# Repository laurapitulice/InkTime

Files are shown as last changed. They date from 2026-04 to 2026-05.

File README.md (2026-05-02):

# ⌚ "InkTime smartwatch" - PCB layout in Autodesk Fusion360
InkTime is an e-paper smartwatch designed for month-class battery life, sunlight-readable time-first UX, and essential phone notifications with basic activity
tracking.
Developed in Autodesk Fusion 360, the PCB layout adheres to the precise dimensions and mounting requirements of the wearable chassis, ensuring a seamless fit and optimal component placement.

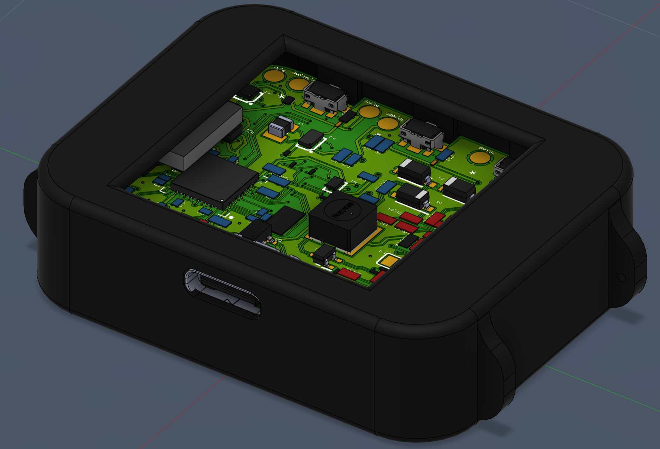
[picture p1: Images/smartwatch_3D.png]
Smartwatch Preview


---

## Hardware Diagram
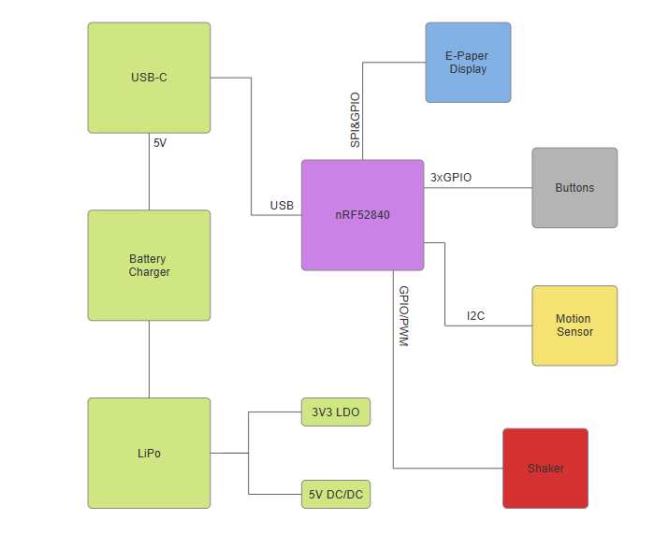
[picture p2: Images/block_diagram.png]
Hardware Diagram


This is an open-hardware wearable based on the nRF52840 microcontroller.

---

## System Architecture

### 1. Microcontroller (MCU)
- **Chip:** Nordic nRF52840 (Cortex-M4F @ 64MHz)
- **Memory:** 1MB Flash, 256KB RAM
- **Radio:** Bluetooth 5.4 Low Energy with integrated ceramic antenna
- **Oscillators:** 32MHz (operational) and 32.768kHz (sleep mode/RTC)

### 2. Power Management
- **Li-Po Charger:** BQ25180 (I2C control, programmable current)
- **Voltage Regulator:** RT6100 Buck-Boost (stable 3.3V output)
- **Battery Monitoring:** MAX17048 Fuel Gauge (ModelGauge algorithm)
- **Charging Interface:** USB-C with USBLC6-2 ESD protection

### 3. Display (E-Paper)
- **Type:** Electronic Paper Display (EPD)
- **Interface:** SPI + Power Gating Control (PWR_EPD)
- **Drive Circuit:** On-board integrated Boost converter (MBR0530 Diodes, L5 10uH) for VGH/VGL generation

### 4. Sensors and Feedback
- **IMU:** BMA421 (Ultra-low power accelerometer connected via I2C)
- **Haptic:** DRV2605 (Vibration driver with integrated effects library via I2C)
- **Input:** 3 mechanical buttons (UP, ENTER, DOWN) with filtering circuits

### 5. Communication Interfaces (I2C Mapping)
| Component | Function | Interface |
| :--- | :--- | :--- |
| **BMA421** | Motion Sensor | I2C |
| **MAX17048** | Battery Status | I2C |
| **DRV2605** | Vibration Motor | I2C |
| **BQ25180** | Charging | I2C |

---

## nRF52840 Pin Mapping

| Pin nRF52840 | Signal | Component | Interface |
|---|---|---|---|
| P0.00/XL1 | XL1 | Crystal X2 (32.768kHz) | XTAL |
| P0.01/XL2 | XL2 | Crystal X2 (32.768kHz) | XTAL |
| P0.05/AIN3  | EPD_CS | E-Paper (J1 FPC) | SPI CS |
| P0.06 | SDA | BMA423, BQ25180, MAX17048, DRV2605 | I2C SDA |
| P0.07 | SCL | BMA423, BQ25180, MAX17048, DRV2605 | I2C SCL |
| P0.08 | IMU_INT1 | BMA423 | GPIO Input |
| P1.08 | IMU_INT2 | BMA423 | GPIO Input |
| P0.11 | PMIC_INT | BQ25180 | GPIO Input |
| P0.12 | HAPTIC_EN  | DRV2605 | GPIO |
| VBUS | VBUS | USB-C (J4) | Power |
| D- | D- | USB-C (J4) / USBLC6 | USB |
| D+ | D+ | USB-C (J4) / USBLC6 | USB |
| P0.13 | SW_UP | Buton Up | GPIO Input |
| P0.14 | SW_ENT | Buton Enter | GPIO Input |
| P0.15 | EPD_DC | E-Paper (J1 FPC) | SPI DC |
| P0.16 | EPD_RST | E-Paper (J1 FPC) | GPIO |
| P0.17 | EPD_BUSY | E-Paper (J1 FPC) | GPIO Input |
| P0.18/RESET | RESET | TC2030-IDC | SWD/GPIO |
| SWDCLK | SWDCLK | TC2030-IDC | SWD |
| SWDIO | SWDIO | TC2030-IDC | SWD |
| P1.02 | SW_DN | Buton Down | GPIO Input |
| P0.10/NFC2  | ALERT | MAX17048 | GPIO Input |
| ANT | RF | Antena 2450AT18B100E | RF |
| P0.02/AIN0  | SCK | E-Paper (J1 FPC) | SPI SCK |
| P0.03/AIN1  | MOSI | E-Paper (J1 FPC) | SPI MOSI |

---

## Hardware Design & PCB Layout

### 1. Component Placement Strategy
The layout process followed a "mechanical-first" approach to ensure perfect alignment with the enclosure:
* **Mechanical Constraints:** Critical components (USB-C connector, side buttons, and the E-Paper FPC connector) were placed first and **locked** to prevent accidental displacement during the routing process.
* **Logical Grouping:** Components were clustered according to their schematic blocks. ICs were placed centrally to their respective functional areas to minimize signal path lengths.
* **Top-Side Only:** All components are placed exclusively on the **TOP layer** to simplify manufacturing and thermal management.
* **Microcontroller:** The **nRF52840** is positioned relatively in the center of the board to maintain balanced access to all peripheral blocks it commands.
* **User Interface:** Test points and tactile buttons were strategically placed along the board edges for easy access during debugging and final assembly.

### 2. Design Rules & Routing
The board utilizes a **2-layer stack-up** with a focus on signal integrity and power stability:
* **Power & Ground:** 
    * Power traces are maintained at a width of **≥ 0.3 mm**, while signal traces are **≥ 0.15 mm**.
    * **Daisy-chaining** was avoided for power; instead, a **branching topology** was used to prevent ground/power loops.
    * Solid **GND polygon pours** are implemented on both Top and Bottom layers, connected by stitching vias to ensure a low-impedance return path.
* **Decoupling:** 100nF capacitors are placed as close as possible to the power pins of each integrated circuit to filter high-frequency noise.
* **Geometry:** Strictly utilized **45° angles** and smooth miters; 90° bends were eliminated to prevent signal reflections and manufacturing "acid traps."
* **Trace Optimization:** Routes were kept as short as possible. Via usage was minimized, only added when top-layer density required a transition to the bottom layer. Traces were kept away from sensitive areas like the crystal oscillator and inductors.

### 3. RF & EMI Management
Special precautions were taken for the wireless and power sections:
* **Antenna Integrity:** The ceramic antenna is isolated in the top-right corner. A strict **keep-out zone** (no copper, traces, or vias) was maintained around the antenna to prevent signal degradation and interference.
* **Inductor Orientation:** Series inductors (**L2, L3**) are positioned **perpendicularly** (90°) to each other to minimize mutual magnetic coupling and unwanted electromagnetic field amplification.
* **Clean Zones:** No traces were routed underneath inductors, the crystal oscillator, or mounting holes to maintain signal purity.

### 4. Design Rule Check (DRC) & Intentional Exceptions
The design was verified against custom DRC rules. Some errors were manually reviewed and accepted based on specific design requirements:
* **Dimension/Clearance Errors:** The USB-C connector and buttons extend slightly beyond the PCB edge for enclosure alignment. These "Dimension" errors are intentional and neglected.
* **Via-in-Pad:** In extremely dense areas where traditional routing was inaccessible, **0.15 mm micro-vias** were placed within pads to facilitate connectivity.
* **3D Modeling:** 3D models were applied to bulky and critical components for enclosure fit-checks; small passives use standard footprint placeholders.

### 5. Final Verification
* **Clear Silkscreen:** All labels and component designators were cleaned and oriented for high legibility (clear and readable).
* **Connectivity Audit:** A final manual and automated netlist audit was performed to ensure 100% routing completion.
* **Manufacturing Ready:** DRC was cleared of all non-intentional errors, ensuring the board meets professional fabrication capabilities.
  
---

## Debug and Programming
- **SWD:** Programming and debugging via Tag-Connect TC2030 connector
- **USB:** Serial communication and charging

---

## Power Consumption and Battery Life

The device is optimized for ultra-low power operation, leveraging the nRF52840's sleep states and power-gating techniques for high-voltage peripherals.

### Estimated Current Consumption
| Operating Mode | Active Components | Estimated Current |
| :--- | :--- | :--- |
| **Deep Sleep** | MCU (System OFF), Fuel Gauge (Sleep) | ~10 µA |
| **Standby (Idle)** | MCU (System ON), IMU (Low-power) | ~0.8 mA |
| **EPD Refresh** | MCU, EPD Boost Circuit, Display | ~12 mA (peak) |
| **Haptic Alert** | MCU, Haptic Driver + Motor | ~80 mA (peak) |

### Battery Life Estimation
Based on a **200mAh** Li-Po battery:
- **Static Time (Always-on):** Over 1 year (EPD retains the image without power).
- **Typical Usage:** ~10-12 days (with BLE active and 1 refresh/hour).
- **Heavy Usage:** ~4-5 days (frequent haptic notifications and updates).
  
---

## Bill of Materials (BOM)

| Component | Description | Qty | Manufacturer | Part Number | Datasheet |
| :--- | :--- | :--- | :--- | :--- | :--- |
| **Microcontroller** | nRF52840 (AQFN-74) | 1 | Nordic Semiconductor | NRF52840_QF | [Link](https://files.seeedstudio.com/wiki/XIAO-BLE/Nano_BLE_MCU-nRF52840_PS_v1.1.pdf) |
| **Antenna** | 2.45GHz Chip Antenna | 1 | Johanson Technology | 2450AT18B100E | [Link](https://www.johansontechnology.com/datasheets/2450AT18B100.pdf) |
| **Accelerometer** | Triaxial low-g 12bit Sensor | 1 | Bosch Sensortec | BMA423 | [Link](https://watchy.sqfmi.com/assets/files/BST-BMA423-DS000-1509600-950150f51058597a6234dd3eaafbb1f0.pdf) |
| **Battery Charger** | Li-Ion/Polymer Charger IC | 1 | Texas Instruments | BQ25180YBGR | [Link](https://www.ti.com/product/BQ25180) |
| **Haptic Driver** | Driver for ERM/LRA | 1 | Texas Instruments | DRV2605YZFR | [Link](https://www.ti.com/product/DRV2605) |
| **Voltage Regulator** | Buck-Boost DC-DC | 1 | Richtek | RT6160AWSC | [Link](https://www.richtek.com/Products/Switching%20Regulators/Buck-Boost%20Converter/RT6160A) |
| **Fuel Gauge** | 1-Cell/2-Cell Fuel Gauge | 1 | Analog Devices | MAX17048G+T10 | [Link](https://www.analog.com/en/products/max17048.html) |
| **Connector (FPC)** | 0.5mm FPC RA SMT 24Ckt | 1 | Molex | 503480-2400 | [Link](https://www.molex.com/en-us/products/part-detail/5034802400) |
| **Connector (USB)** | USB Type-C 16-pin | 1 | Kinghelm | KH-TYPE-C-16P | [Link](https://jlcpcb.com/api/file/downloadByFileSystemAccessId/8588905154556923904) |
| **ESD Protection** | Low Cap. ESD Protection | 1 | STMicroelectronics | USBLC6-2SC6Y | [Link](https://www.st.com/en/protection-devices/usblc6-2.html) |
| **MOSFET (P)** | P-channel 20V/4.2A | 1 | Diodes Inc. | DMG2305UX-7 | [Link](https://www.lcsc.com/datasheet/C469327.pdf) |
| **MOSFET (N)** | N-channel 30V 1.5A | 1 | Vishay Siliconix | SI1308EDL-T1-GE3 | [Link](https://www.lcsc.com/datasheet/C469327.pdf) |
| **Schottky Diode** | 30V 0.5A Schottky | 3 | ON Semiconductor | MBR0530 | [Link](https://www.onsemi.com/pdf/datasheet/mbr0530t1-d.pdf) |
| **Inductor** | SMD Inductor 0.47µH | 1 | TDK | FTC252012SR47MBCA | [Link](https://jlcpcb.com/partdetail/6763488-FTC252012SR47MBCA/C5832368) |
| **Inductor** | Power Inductor 68uH | 1 | Wurth Electronics | 744043680 | [Link](https://www.we-online.com/en/components/products/WE-TPC) |
| **Switches** | Tactile Switches | 3 | Panasonic | EVP-AKE31A | [Link](https://wmsc.lcsc.com/wmsc/upload/file/pdf/v2/lcsc/2301111010_PANASONIC-EVPAKE31A_C569760.pdf) |
| **Crystals** | 32MHz & 32.768kHz | 2 | Generic/Nordic | X1, X2 | [Link1](https://wmsc.lcsc.com/wmsc/upload/file/pdf/v2/lcsc/2312080231_NDK-NX2016SA-32MHZ-EXS00A-CS11336_C6134317.pdf), [Link2](https://jlcpcb.com/partdetail/SeikoEpson-FC_135_32_7680KAA3/C2650472) |
| **Test Connector** | CABLE ADAPTER 6 POS | 1 | Tag Connect | TC2030-IDC | [Link](https://www.tag-connect.com/wp-content/uploads/bsk-pdf-manager/2019/12/TC2030-IDC-Datasheet-Rev-B.pdf) |

** The design and implementation of this PCB were based on the technical guidelines and reference designs provided by [OCW](https://ocw.cs.pub.ro/courses/tsc/proiect2026).

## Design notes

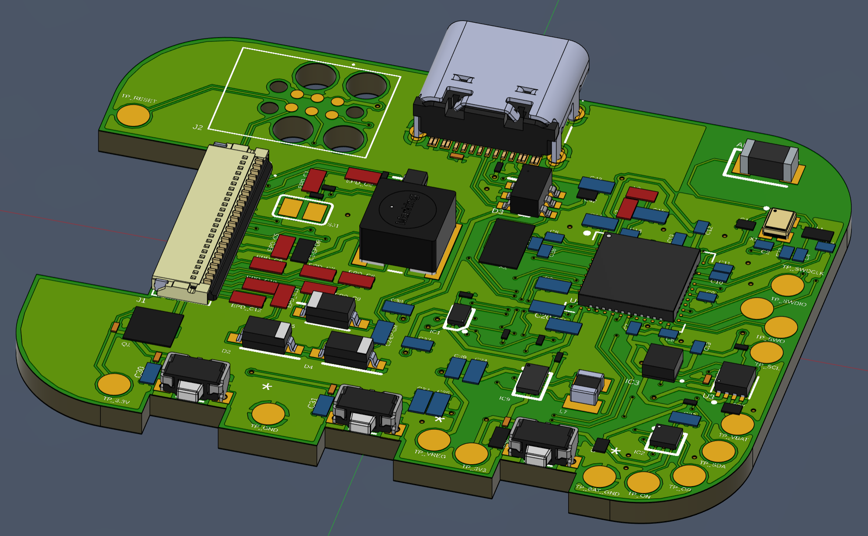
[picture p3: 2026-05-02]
Images/PCB_3D_side_view.png

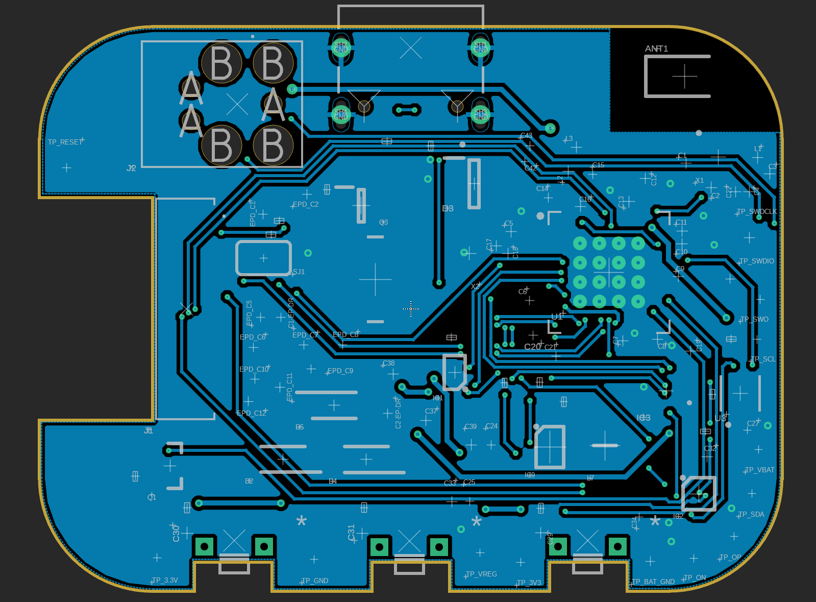
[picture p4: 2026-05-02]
Images/PCB_2D_bottom_layer.png

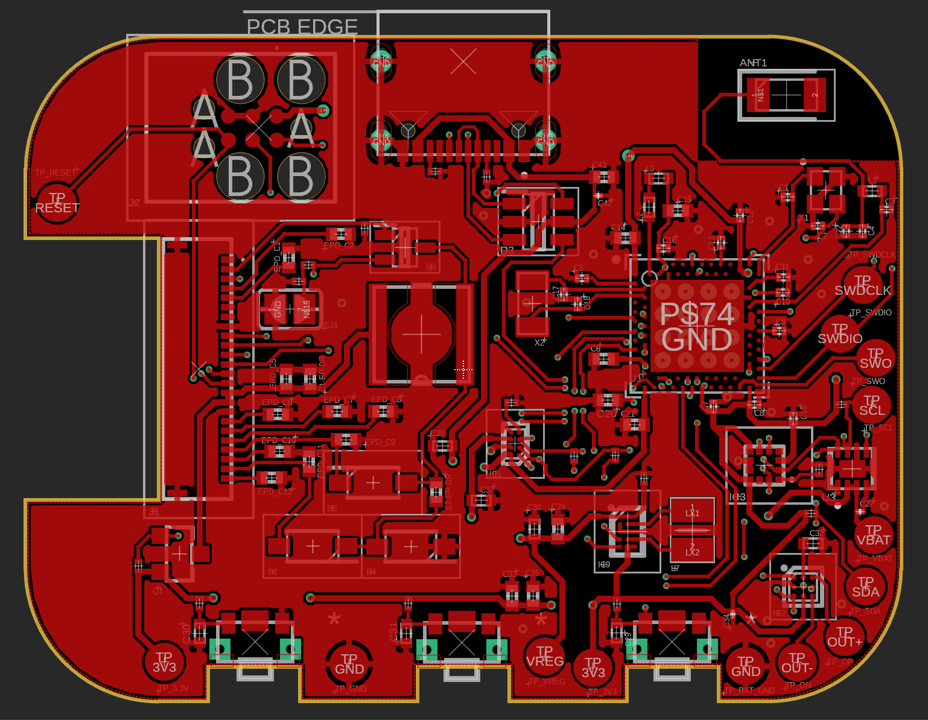
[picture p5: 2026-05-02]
Images/PCB_2D_top_layer.png

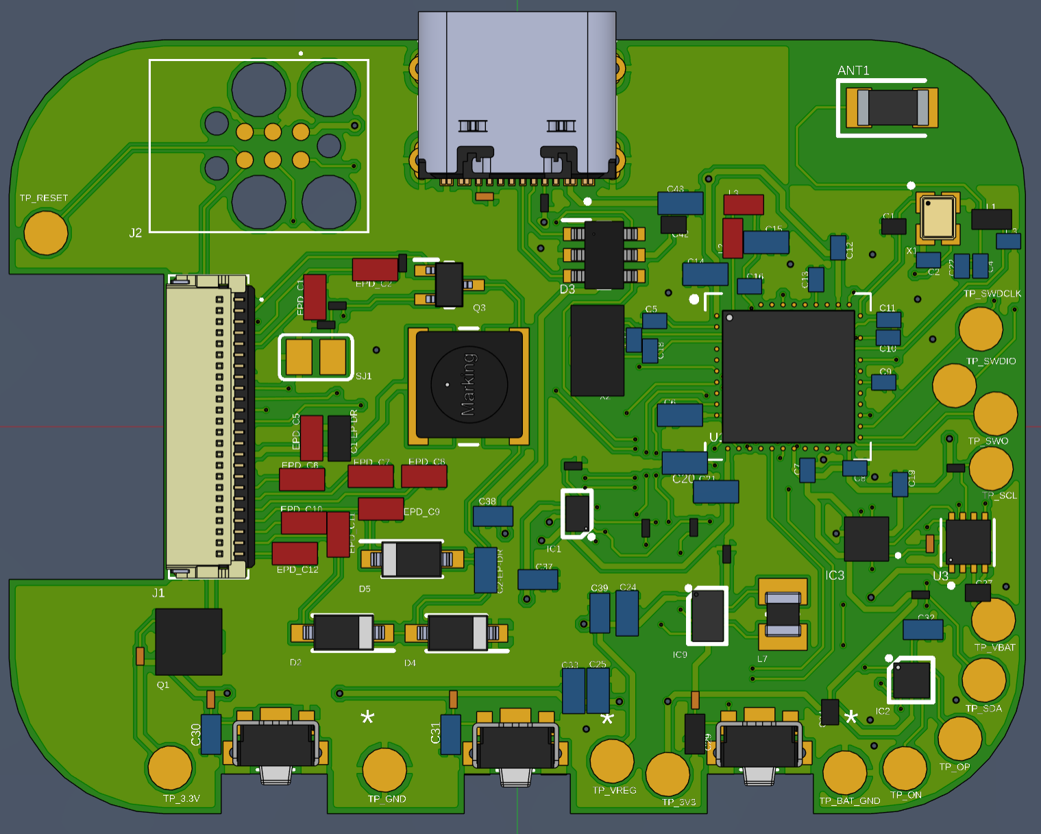
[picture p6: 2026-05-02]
Images/PCB_3D_top_view.png

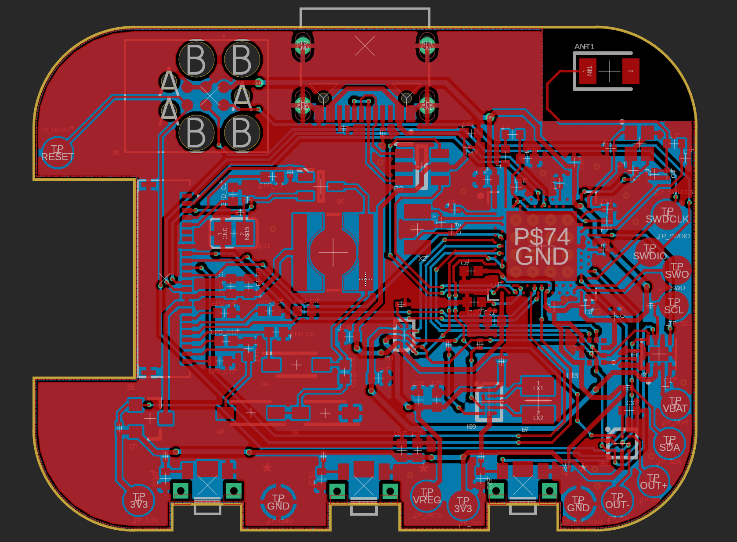
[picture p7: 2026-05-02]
Images/PCB_2D.png

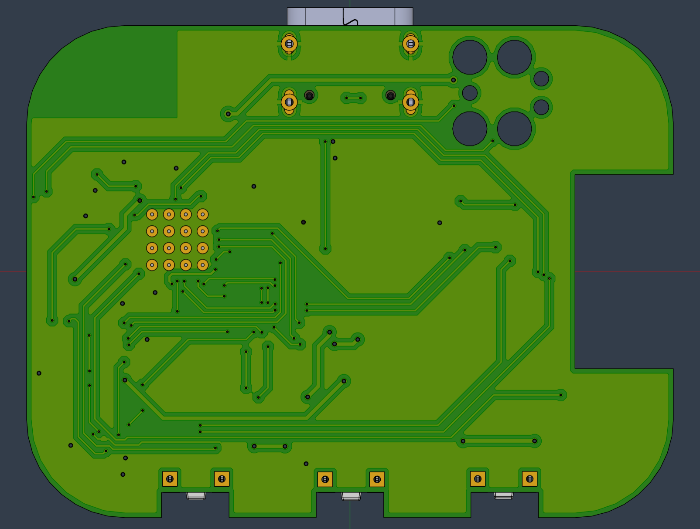
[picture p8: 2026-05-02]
Images/PCB_3D_bottom_view.png

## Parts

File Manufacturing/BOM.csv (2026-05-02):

Qty | Value | Device | Package | Parts | Description | ARROW_PART_NUMBER | ARROW_PRICE-STOCK | AVAILABILITY | CHECK_PRICES | COPYRIGHT | DESCRIPTION | DIGI-KEY_PART_NUMBER_1 | DIGI-KEY_PART_NUMBER_2 | DIGI-KEY_PART_NUMBER_3 | HEIGHT | JLCPCB | MANUFACTURER_NAME | MANUFACTURER_PART_NUMBER | MF | MFR_NAME | MOUSER_PART_NUMBER | MOUSER_PRICE-STOCK | MP | PACKAGE | POPULARITY | PRICE | PROD_ID | PURCHASE-URL | SNAPEDA_LINK | TP_SIGNAL_NAME | VALUE
1 | 0 | CPF0201D7K68C1_CPF0201D7K68C1 | CPF0201D7K68C1_0201 | R3 | 7.68k 0201 Thin Film Surface Mount Fixed Resistor +/-0.5% 0.031W CPF0201D7K68C1
2 | 0 | ERA-1AEB3401C_CPF0201D7K68C1 | ERA-1AEB3401C_0201 | R2, R4 | 7.68k 0201 Thin Film Surface Mount Fixed Resistor +/-0.5% 0.031W CPF0201D7K68C1
1 | 0 | ESP32_C6_LIBRARY_7_JUMPER_SJ | ESP32_C6_LIBRARY_7_JUMPER_SJ | SJ1 | SMD solder JUMPER |  |  |  |  |  |  |  |  |  |  |  |  |  |  |  |  |  |  |  | 3
1 | 0.1uF | GRM011R60J152KE01L_1_GRM011R60J152KE01L | GRM011R60J152KE01L_1_0201 | C23 | Check availability
3 | 0.1uF | GRM011R60J152KE01L_2_GRM011R60J152KE01L | GRM011R60J152KE01L_2_CAPC0201X13N | C27, C34, C42 | Check availability |  |  | In Stock | https://www.snapeda.com/parts/GRM011R60J152KE01L/Murata/view-part/?ref=eda |  | SMD Capacitor X5R(EIA) with Capacitance: 1500pF Tol. 10%. Rated Voltage: 6.3Vdc |  |  |  |  |  |  |  | Murata |  |  |  | GRM011R60J152KE01L | 0201 Murata |  | None |  |  | https://www.snapeda.com/parts/GRM011R60J152KE01L/Murata/view-part/?ref=snap
1 | 0.47 | ERA-1AEB3401C_CPF0201D7K68C1 | ERA-1AEB3401C_0201 | R1_EP_DR | 7.68k 0201 Thin Film Surface Mount Fixed Resistor +/-0.5% 0.031W CPF0201D7K68C1
1 | 1.0uF | PERFECT_0402_CAP_0402 | PERFECT_0402_0402 | C15 | 0402 (1005 Metric)
5 | 100nF | NORDIC_NRF_3_CAPACITOR_0201_L | NORDIC_NRF_3_RESC0201_L | C5, C7, C8, C12, C19 | Generic chip capacitor
1 | 100pF | NORDIC_NRF_3_CAPACITOR_0201_L | NORDIC_NRF_3_RESC0201_L | C11 | Generic chip capacitor
1 | 10K | CPF0201D7K68C1_CPF0201D7K68C1 | CPF0201D7K68C1_0201 | R_PWR_EPD | 7.68k 0201 Thin Film Surface Mount Fixed Resistor +/-0.5% 0.031W CPF0201D7K68C1
2 | 10K | ERA-1AEB3401C_CPF0201D7K68C1 | ERA-1AEB3401C_0201 | R2_EP_DR, R9 | 7.68k 0201 Thin Film Surface Mount Fixed Resistor +/-0.5% 0.031W CPF0201D7K68C1
3 | 10k | CPF0201D7K68C1_CPF0201D7K68C1 | CPF0201D7K68C1_0201 | R5, R7, R8 | 7.68k 0201 Thin Film Surface Mount Fixed Resistor +/-0.5% 0.031W CPF0201D7K68C1
1 | 10uF | NORDIC_NRF_3_CAPACITOR_0402_L | NORDIC_NRF_3_RESC0402_L | C39 | Generic chip capacitor
2 | 10uF | PERFECT_0402_CAP_0402 | PERFECT_0402_0402 | C1-EP-DR, C24 | 0402 (1005 Metric)
1 | 10uH | NORDIC_NRF_2_INDUCTOR_0402_L | NORDIC_NRF_2_RESC0402_L | L2 | Generic chip inductor
4 | 12pF | NORDIC_NRF_3_CAPACITOR_0201_L | NORDIC_NRF_3_RESC0201_L | C1, C2, C17, C18 | Generic chip capacitor
1 | 15nH | NORDIC_NRF_2_INDUCTOR_0402_L | NORDIC_NRF_2_RESC0402_L | L3 | Generic chip inductor
2 | 1pF | NORDIC_NRF_3_CAPACITOR_0201_L | NORDIC_NRF_3_RESC0201_L | C3, C4 | Generic chip capacitor
6 | 1uF | NORDIC_NRF_3_CAPACITOR_0402_L | NORDIC_NRF_3_RESC0402_L | C29, C30, C31, C32, C37, C38 | Generic chip capacitor
10 | 1uF/50V | PERFECT_0402_CAP_0402 | PERFECT_0402_0402 | EPD_C1, EPD_C2, EPD_C5, EPD_C6, EPD_C7, EPD_C8, EPD_C9, EPD_C10, EPD_C11, EPD_C12 | 0402 (1005 Metric)
1 | 2.2 | ERA-1AEB3401C_CPF0201D7K68C1 | ERA-1AEB3401C_0201 | R_TYPE_SEL | 7.68k 0201 Thin Film Surface Mount Fixed Resistor +/-0.5% 0.031W CPF0201D7K68C1
3 | 2025-10-22_07-23-44_LIBRARY_EVP-AKE31ASW_EVP-AKE31A_PAN | 2025-10-22_07-23-44_LIBRARY_EVP-AKE31ASW_EVP-AKE31A_PAN | 2025-10-22_07-23-44_LIBRARY_SW_EVP-AKE31A_PAN | SW_DN, SW_ENT, SW_UP |  |  |  |  |  | Copyright (C) 2025 Ultra Librarian. All rights reserved. |  | P123437TR-ND | P123437CT-ND | P123437DKR-ND |  |  | Panasonic | EVP-AKE31A
2 | 22uF | PERFECT_0402_CAP_0402 | PERFECT_0402_0402 | C25, C33 | 0402 (1005 Metric)
1 | 2450AT18B100E_2450AT18B100E | 2450AT18B100E_2450AT18B100E | 2450AT18B100E_ANTC3216X140N | ANT1 | Antennas 2.45GHz ANTENNA | 2450AT18B100E | https://www.arrow.com/en/products/2450at18b100e/johanson-dielectrics?utm_currency=USD&region=nac |  |  |  | Antennas 2.45GHz ANTENNA |  |  |  | 1.4mm |  | JOHANSON TECHNOLOGY | 2450AT18B100E |  |  | 609-2450AT18B100E | https://www.mouser.co.uk/ProductDetail/Johanson-Technology/2450AT18B100E?qs=yCnrNFeXz%252Bh5MFsFIXGZGA%3D%3D
1 | 3.9nH | NORDIC_NRF_2_INDUCTOR_0402_L | NORDIC_NRF_2_RESC0402_L | L1 | Generic chip inductor
1 | 32.768kHz | NORDIC_NRF_1_XTAL_32KHZ | NORDIC_NRF_1_XTAL_3215_N | X2
1 | 32MHz | NORDIC_NRF_XTAL_32MHZ | NORDIC_NRF_BT-XTAL_2016_N | X1
2 | 3K3 | ERA-1AEB3401C_CPF0201D7K68C1 | ERA-1AEB3401C_0201 | R17, R18 | 7.68k 0201 Thin Film Surface Mount Fixed Resistor +/-0.5% 0.031W CPF0201D7K68C1
5 | 4.7uF | PERFECT_0402_CAP_0402 | PERFECT_0402_0402 | C6, C14, C20, C21, C43 | 0402 (1005 Metric)
1 | 4.7uF/25V | PERFECT_0402_CAP_0402 | PERFECT_0402_0402 | C2-EP-DR | 0402 (1005 Metric)
1 | 47nF | NORDIC_NRF_3_CAPACITOR_0201_L | NORDIC_NRF_3_RESC0201_L | C16 | Generic chip capacitor
1 | 503480-2400 | 503480-2400_503480-2400 | 503480-2400_5034802400 | J1 | FFC & FPC Connectors 0.5mm FPC RA SMT Dual Contact 24Ckt |  |  |  |  |  | FFC & FPC Connectors 0.5mm FPC RA SMT Dual Contact 24Ckt |  |  |  | 1.87mm |  | Molex | 503480-2400 |  |  | 538-503480-2400 | https://www.mouser.co.uk/ProductDetail/Molex/503480-2400?qs=OAhjpuo3Vu7efIoxFh9AOw%3D%3D
2 | 5K1 | CPF0201D7K68C1_CPF0201D7K68C1 | CPF0201D7K68C1_0201 | R1_USB, R2_USB | 7.68k 0201 Thin Film Surface Mount Fixed Resistor +/-0.5% 0.031W CPF0201D7K68C1
1 | 68 uH | ESP32_C6_LIBRARY_2_744043680IND_4828-WE-TPC_WRE | ESP32_C6_LIBRARY_2_IND_4828-WE-TPC_WRE | L5 |  |  |  |  |  | Copyright (C) 2024 Ultra Librarian. All rights reserved. |  |  |  |  |  |  |  | 744043680 |  | Wurth Electronics
1 | 820pF N.C. | NORDIC_NRF_3_CAPACITOR_0201_L | NORDIC_NRF_3_RESC0201_L | C9 | Generic chip capacitor
1 | BMA423 | BMA423_BMA423 | BMA423_BMA423 | IC3 | Accelerometers Triaxial low-g 12bit Acceleration Sensor | BMA423 | https://www.arrow.com/en/products/bma423/bosch |  |  |  | Accelerometers Triaxial low-g 12bit Acceleration Sensor |  |  |  | 1mm |  | BOSCH | BMA423 |  |  | 262-BMA423 | https://www.mouser.co.uk/ProductDetail/Bosch-Sensortec/BMA423?qs=HXFqYaX1Q2xC%252BSgeGoX3mg%3D%3D
1 | BQ25180YBGR | BQ25180YBGR_BQ25180YBGR | BQ25180YBGR_BGA8C40P2X4_100X155X50 | IC1 | Charger IC Lithium Ion/Polymer, Lithium Iron Phosphate 8-DSBGA (1.6x1.1) | BQ25180YBGR | https://www.arrow.com/en/products/bq25180ybgr/texas-instruments?utm_currency=USD&region=nac |  |  |  | Charger IC Lithium Ion/Polymer | Lithium Iron Phosphate 8-DSBGA (1.6x1.1) |  |  |  | 0.5mm |  | Texas Instruments | BQ25180YBGR |  |  | 595-BQ25180YBGR | https://www.mouser.co.uk/ProductDetail/Texas-Instruments/BQ25180YBGR?qs=doiCPypUmgEWjAK%252BJAX6Tw%3D%3D
1 | DMG2305UX-7 20V/4.2A/52mO/1.4W | ESP32_C6_LIBRARY_4_ESP32_WROVER_SPARKFUN-DISCRETESEMI_MOSFET_PCH-DMG2305UX-7 | ESP32_C6_LIBRARY_4_ESP32_C6_LIBRARY_4_ESP32_C6_LIBRARY_4_ESP32_C6_LIBRARY_4_ESP32_WROVER_SPARKFUN-DISCRETESEMI_SOT23-3 | Q1 | P-channel MOSFETs |  |  |  |  |  |  |  |  |  |  |  |  |  |  |  |  |  |  |  |  |  | TRAN-14388 |  |  |  | 20V/4.2A/52mO/1.4W
1 | DRV2605YZFR | DRV2605YZFR_DRV2605YZFR | DRV2605YZFR_BGA9C50P3X3_144X144X62 | IC2 | Haptic Driver for ERM/LRA with Built-In Library and Smart Loop Architecture | DRV2605YZFR | https://www.arrow.com/en/products/drv2605yzfr/texas-instruments?region=nac |  |  |  | Haptic Driver for ERM/LRA with Built-In Library and Smart Loop Architecture |  |  |  | 0.625mm |  | Texas Instruments | DRV2605YZFR
1 | FTC252012SR47MBCA | MLP2016SR47MT0S1_FTC252012SR47MBCA | MLP2016SR47MT0S1_INDC2016X100N | L7 | SMD / SMT Inductors (Coils), L=0.47?H, L x W x T : |  |  |  |  |  | SMD / SMT Inductors (Coils) | L=0.47?H | L x W x T : |  |  |  | 1mm | https://jlcpcb.com/partdetail/6763488-FTC252012SR47MBCA/C5832368 | TDK | FTC252012SR47MBCA
14 | HECTOR_WATCH_1_TPTP20R | HECTOR_WATCH_1_TPTP20R | HECTOR_WATCH_1_TP20R | TP_3.3V, TP_3V3, TP_BAT_GND, TP_GND, TP_ON, TP_OP, TP_RESET, TP_SCL, TP_SDA, TP_SWDCLK, TP_SWDIO, TP_SWO, TP_VBAT, TP_VREG | Test pad |  |  |  |  |  |  |  |  |  |  |  |  |  |  |  |  |  |  |  | 2
1 | KH-TYPE-C-16P | KH-TYPE-C-16P_KH-TYPE-C-16P | KH-TYPE-C-16P_KINGHELM_KH-TYPE-C-16P | J4 | Check availability |  |  | Not in stock | https://www.snapeda.com/parts/KH-TYPE-C-16P/Kinghelm/view-part/?ref=eda |  |  |  |  |  |  |  |  |  | kinghelm |  |  |  | KH-TYPE-C-16P | None |  | None |  |  | https://www.snapeda.com/parts/KH-TYPE-C-16P/Kinghelm/view-part/?ref=snap
1 | MAX17048G+T10 | ESP32_C6_LIBRARY_MAX17048G+T10 | ESP32_C6_LIBRARY_SON50P200X200X80-9N | U3 | Check availability |  |  | In Stock | https://www.snapeda.com/parts/MAX17048G+T10/Analog+Devices/view-part/?ref=eda |  | 3µA 1-Cell/2-Cell Fuel Gauge with ModelGauge |  |  |  |  |  |  |  | Analog Devices |  |  |  | MAX17048G+T10 | TDFN-8 Maxim |  | None |  | https://www.snapeda.com/api/url_track_click_mouser/?unipart_id=329239&manufacturer=Analog Devices&part_name=MAX17048G+T10&search_term=None | https://www.snapeda.com/parts/MAX17048G+T10/Analog+Devices/view-part/?ref=snap
3 | MBR0530 | ESP32_C6_LIBRARY_5_MBR0530 | ESP32_C6_LIBRARY_5_SOD3716X135N | D2, D4, D5 | ON SEMICONDUCTOR - MBR0530 - DIODE, SCHOTTKY, 0.5A, 30V, SOD-123 |  |  | In Stock | https://www.snapeda.com/parts/MBR0530/Onsemi/view-part/?ref=eda |  | Diode Schottky 30 V 500mA Surface Mount SOD-123 |  |  |  |  |  |  |  | ON Semiconductor |  |  |  | MBR0530 | SOD-123-2 ON Semiconductor |  | None |  | https://www.snapeda.com/api/url_track_click_mouser/?unipart_id=179458&manufacturer=ON Semiconductor&part_name=MBR0530&search_term=None | https://www.snapeda.com/parts/MBR0530/Onsemi/view-part/?ref=snap
3 | N.C. | NORDIC_NRF_3_CAPACITOR_0201_L | NORDIC_NRF_3_RESC0201_L | C10, C13, C22 | Generic chip capacitor
1 | NRF52840_QF | NORDIC_NRF_4_NRF52840_QF | NORDIC_NRF_4_AQFN50P700X700X85_HS-74N | U1 | nRF52840
1 | RT6160AWSC | RT6160AWSC_RT6160AWSC | RT6160AWSC_BGA15C40P3X5_140X230X60 | IC9 | Buck-Boost Regulator Positive Output Step-Up/Step-Down I2C DC-DC Controller IC 15-WL-CSP (BSC) (1.4x2.3) |  |  |  |  |  | Buck-Boost Regulator Positive Output Step-Up/Step-Down I2C DC-DC Controller IC 15-WL-CSP (BSC) (1.4x2.3) |  |  |  | 0.6mm |  | RICHTEK | RT6160AWSC |  |  | 835-RT6160AWSC | https://www.mouser.co.uk/ProductDetail/Richtek/RT6160AWSC?qs=amGC7iS6iy%2FLd9PSoixZXQ%3D%3D
1 | SI1308EDL-T1-GE3 | ESP32_C6_LIBRARY_6_SI1308EDL-T1-GE3 | ESP32_C6_LIBRARY_6_SOT65P210X110-3N | Q3 | MOSFET N-Ch 30V 1.5A TrenchFET SC70 Vishay Si1308EDL-T1-GE3 N-channel MOSFET Transistor, 1.5 A, 30 V, 3-Pin SC-70 |  |  | In Stock | https://www.snapeda.com/parts/SI1308EDL-T1-GE3/Vishay+Siliconix/view-part/?ref=eda |  | Si1308EDL-T1-GE3 N-channel MOSFET Transistor | 1.5 A | 30 V | 3-Pin SC-70 | Siliconix / Vishay SI1308EDL-T1-GE3 |  |  |  |  |  |  |  | Vishay Siliconix |  |  |  | SI1308EDL-T1-GE3 | SOT-323 Vishay Semiconductor |  | None |  | https://www.snapeda.com/api/url_track_click_mouser/?unipart_id=274603&manufacturer=Vishay Siliconix&part_name=SI1308EDL-T1-GE3&search_term=None
1 | TC2030-IDC | TC2030-IDC_TC2030-IDC | TC2030-IDC_TC2030IDC | J2 | CABLE ADAPTER 6 POS |  |  |  |  |  | CABLE ADAPTER 6 POS |  |  |  | 19mm |  | Tag Connect | TC2030-IDC
1 | USBLC6-2SC6Y | ESP32_C6_LIBRARY_3_USBLC6-2SC6Y | ESP32_C6_LIBRARY_3_SOT95P280X145-6N | D3 | Low Cap. ESD Protection Auto SOT-23-6 STMicroelectronics USBLC6-2SC6Y, Dual Uni-Directional TVS Diode Array, 6-Pin SOT-23 |  |  | In Stock | https://www.snapeda.com/parts/USBLC6-2SC6Y/STMicroelectronics/view-part/?ref=eda |  | 17V Clamp 5A (8/20µs) Ipp Tvs Diode Surface Mount SOT-23-6 |  |  |  |  |  |  |  | STMicroelectronics |  |  |  | USBLC6-2SC6Y | SOT-23-6 STMicroelectronics |  | None |  |  | https://www.snapeda.com/parts/USBLC6-2SC6Y/STMicroelectronics/view-part/?ref=snap

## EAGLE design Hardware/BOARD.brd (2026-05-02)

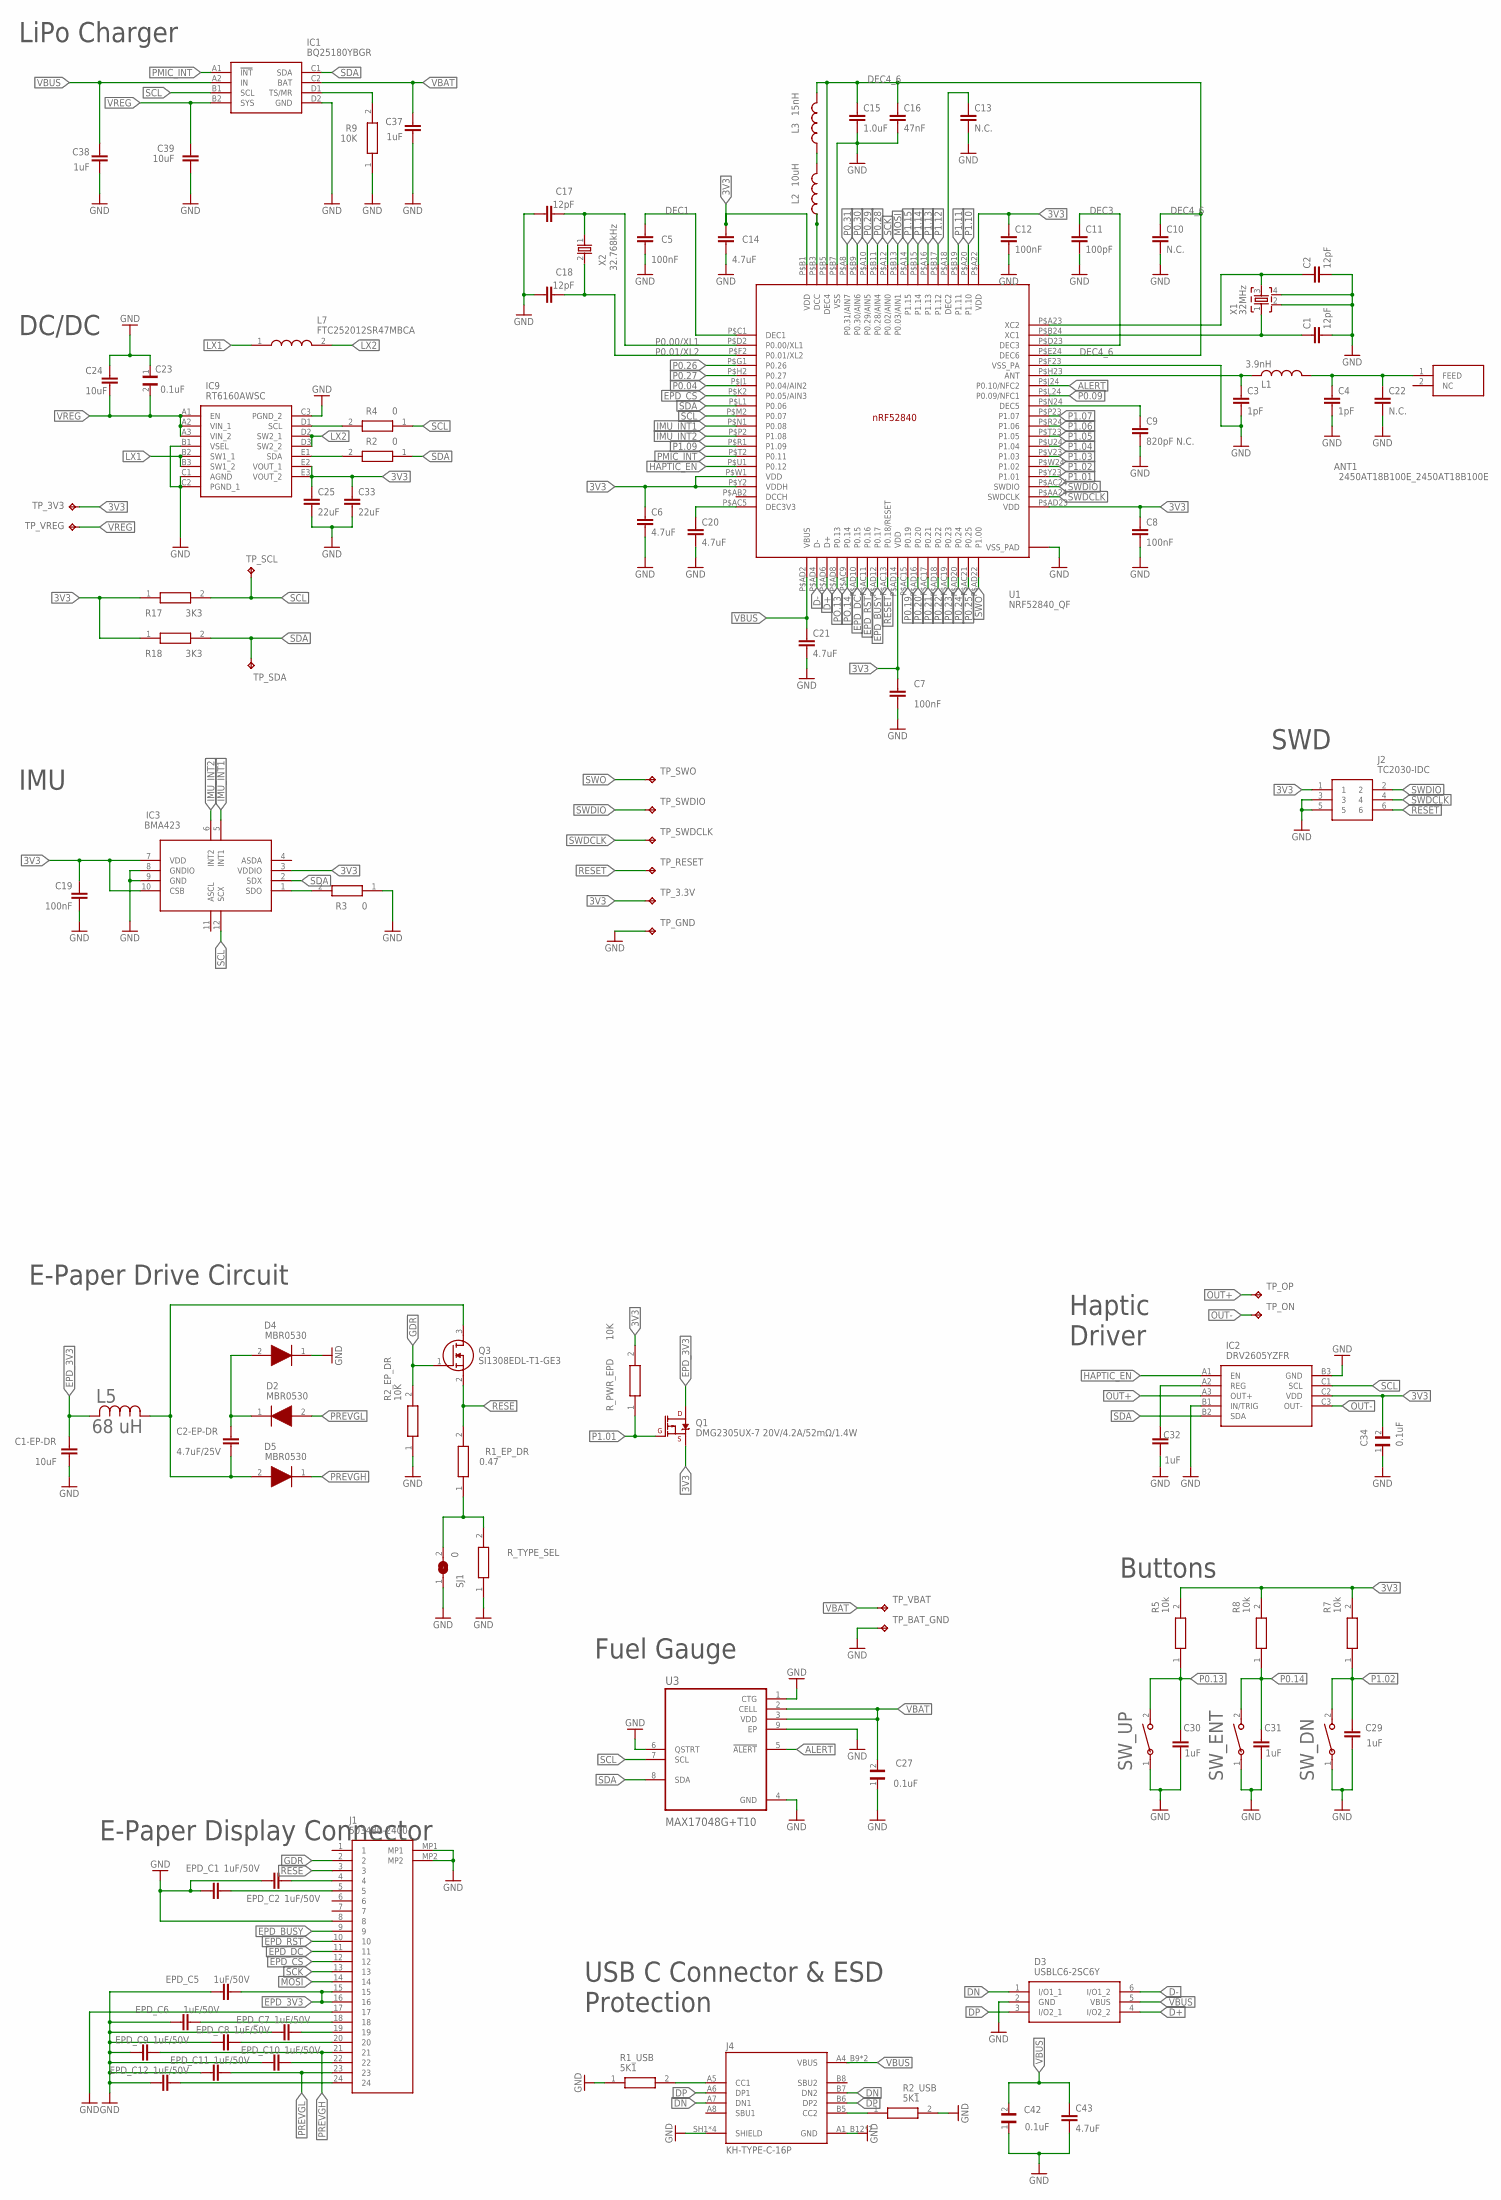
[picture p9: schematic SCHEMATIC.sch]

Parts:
ANT1: 2450AT18B100E_2450AT18B100E; 2450AT18B100E_ANTC3216X140N
C1, C2, C17, C18: 12pF; NORDIC_NRF_3_RESC0201_L
C1-EP-DR, C24: 10uF; PERFECT_0402_0402
C2-EP-DR: 4.7uF/25V; PERFECT_0402_0402
C3, C4: 1pF; NORDIC_NRF_3_RESC0201_L
C5, C7, C8, C12, C19: 100nF; NORDIC_NRF_3_RESC0201_L
C6, C14, C20, C21, C43: 4.7uF; PERFECT_0402_0402
C9: 820pF N.C.; NORDIC_NRF_3_RESC0201_L
C10, C13, C22: N.C.; NORDIC_NRF_3_RESC0201_L
C11: 100pF; NORDIC_NRF_3_RESC0201_L
C15: 1.0uF; PERFECT_0402_0402
C16: 47nF; NORDIC_NRF_3_RESC0201_L
C23: 0.1uF; GRM011R60J152KE01L_1_0201
C25, C33: 22uF; PERFECT_0402_0402
C27, C34, C42: 0.1uF; GRM011R60J152KE01L_2_CAPC0201X13N
C29, C30, C31, C32, C37, C38: 1uF; NORDIC_NRF_3_RESC0402_L
C39: 10uF; NORDIC_NRF_3_RESC0402_L
D2, D4, D5: MBR0530; ESP32_C6_LIBRARY_5_SOD3716X135N
D3: USBLC6-2SC6Y; ESP32_C6_LIBRARY_3_SOT95P280X145-6N
EPD_C1, EPD_C2, EPD_C5, EPD_C6, EPD_C7, EPD_C8, EPD_C9, EPD_C10, EPD_C11, EPD_C12: 1uF/50V; PERFECT_0402_0402
IC1: BQ25180YBGR; BQ25180YBGR_BGA8C40P2X4_100X155X50
IC2: DRV2605YZFR; DRV2605YZFR_BGA9C50P3X3_144X144X62
IC3: BMA423; BMA423_BMA423
IC9: RT6160AWSC; RT6160AWSC_BGA15C40P3X5_140X230X60
J1: 503480-2400; 503480-2400_5034802400
J2: TC2030-IDC; TC2030-IDC_TC2030IDC
J4: KH-TYPE-C-16P; KH-TYPE-C-16P_KINGHELM_KH-TYPE-C-16P
L1: 3.9nH; NORDIC_NRF_2_RESC0402_L
L2: 10uH; NORDIC_NRF_2_RESC0402_L
L3: 15nH; NORDIC_NRF_2_RESC0402_L
L5: 68 uH; ESP32_C6_LIBRARY_2_IND_4828-WE-TPC_WRE
L7: FTC252012SR47MBCA; MLP2016SR47MT0S1_INDC2016X100N
Q1: DMG2305UX-7 20V/4.2A/52mΩ/1.4W; ESP32_C6_LIBRARY_4_ESP32_C6_LIBRARY_4_ESP32_C6_LIBRARY_4_ES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
Q3: SI1308EDL-T1-GE3; ESP32_C6_LIBRARY_6_SOT65P210X110-3N
R1_EP_DR: 0.47; ERA-1AEB3401C_0201
R1_USB, R2_USB: 5K1; CPF0201D7K68C1_0201
R2, R4: 0; ERA-1AEB3401C_0201
R2_EP_DR, R9: 10K; ERA-1AEB3401C_0201
R3: 0; CPF0201D7K68C1_0201
R5, R7, R8: 10k; CPF0201D7K68C1_0201
R17, R18: 3K3; ERA-1AEB3401C_0201
R_PWR_EPD: 10K; CPF0201D7K68C1_0201
R_TYPE_SEL: 2.2; ERA-1AEB3401C_0201
SJ1: 0; ESP32_C6_LIBRARY_7_JUMPER_SJ
SW_DN: 2025-10-22_07-23-44_LIBRARY_EVP-AKE31ASW_EVP-AKE3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; 2025-10-22_07-23-44_LIBRARY_SW_EVP-AKE31A_PAN
SW_ENT: 2025-10-22_07-23-44_LIBRARY_EVP-AKE31ASW_EVP-AKE3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; 2025-10-22_07-23-44_LIBRARY_SW_EVP-AKE31A_PAN
SW_UP: 2025-10-22_07-23-44_LIBRARY_EVP-AKE31ASW_EVP-AKE3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; 2025-10-22_07-23-44_LIBRARY_SW_EVP-AKE31A_PAN
TP_3.3V, TP_3V3: HECTOR_WATCH_1_TPTP20R; HECTOR_WATCH_1_TP20R
TP_BAT_GND: HECTOR_WATCH_1_TPTP20R; HECTOR_WATCH_1_TP20R
TP_GND: HECTOR_WATCH_1_TPTP20R; HECTOR_WATCH_1_TP20R
TP_ON: HECTOR_WATCH_1_TPTP20R; HECTOR_WATCH_1_TP20R
TP_OP: HECTOR_WATCH_1_TPTP20R; HECTOR_WATCH_1_TP20R
TP_RESET: HECTOR_WATCH_1_TPTP20R; HECTOR_WATCH_1_TP20R
TP_SCL: HECTOR_WATCH_1_TPTP20R; HECTOR_WATCH_1_TP20R
TP_SDA: HECTOR_WATCH_1_TPTP20R; HECTOR_WATCH_1_TP20R
TP_SWDCLK: HECTOR_WATCH_1_TPTP20R; HECTOR_WATCH_1_TP20R
TP_SWDIO: HECTOR_WATCH_1_TPTP20R; HECTOR_WATCH_1_TP20R
TP_SWO: HECTOR_WATCH_1_TPTP20R; HECTOR_WATCH_1_TP20R
TP_VBAT: HECTOR_WATCH_1_TPTP20R; HECTOR_WATCH_1_TP20R
TP_VREG: HECTOR_WATCH_1_TPTP20R; HECTOR_WATCH_1_TP20R
U1: NRF52840_QF; NORDIC_NRF_4_AQFN50P700X700X85_HS-74N
U3: MAX17048G+T10; ESP32_C6_LIBRARY_SON50P200X200X80-9N
X1: 32MHz; NORDIC_NRF_BT-XTAL_2016_N
X2: 32.768kHz; NORDIC_NRF_1_XTAL_3215_N

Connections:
3V3: C6.1, C7.1, C8.1, C12.1, C14.1, C19.1, C25.1, C33.1, C34.2, IC2.C2 (VDD), IC3.3 (VDDIO), IC3.7 (VDD), IC3.10 (CSB), IC9.E2 (VOUT_1), IC9.E3 (VOUT_2), J2.1, Q1.2 (S), R5.2, R7.2, R8.2, R17.1, R18.1, R_PWR_EPD.2, TP_3.3V.TP, TP_3V3.TP, U1.P$A22 (VDD), U1.P$AD14 (VDD), U1.P$AD23 (VDD), U1.P$B1 (VDD), U1.P$W1 (VDD), U1.P$Y2 (VDDH)
ALERT: U1.P$J24 (P0.10/NFC2), U3.5 (!ALERT)
D+: D3.4 (I/O2_2), U1.P$AD6 (D+)
D-: D3.6 (I/O1_2), U1.P$AD4 (D-)
DEC1: C5.1, U1.P$C1 (DEC1)
DEC3: C11.1, U1.P$D23 (DEC3)
DEC4_6: C10.1, C15.1, C16.1, L3.2, U1.P$B5 (DEC4), U1.P$E24 (DEC6)
DN: D3.1 (I/O1_1), J4.A7 (DN1), J4.B7 (DN2)
DP: D3.3 (I/O2_1), J4.A6 (DP1), J4.B6 (DP2)
EPD_3V3: C1-EP-DR.1, EPD_C5.2, J1.15, J1.16, L5.2, Q1.3 (D)
EPD_BUSY: J1.9, U1.P$AD12 (P0.17)
EPD_CS: J1.12, U1.P$K2 (P0.05/AIN3)
EPD_DC: J1.11, U1.P$AD10 (P0.15)
EPD_RST: J1.10, U1.P$AC11 (P0.16)
GDR: J1.2, Q3.1 (G), R2_EP_DR.2
GND: C1.2, C1-EP-DR.2, C2.2, C3.2, C4.2, C5.2, C6.2, C7.2, C8.2, C9.2, C10.2, C11.2, C12.2, C13.2, C14.2, C15.2, C16.2, C17.1, C18.1, C19.2, C20.2, C21.2, C22.2, C23.1, C24.1, C25.2, C27.1, C29.1, C30.1, C31.1, C32.1, C33.2, C34.1, C37.1, C38.1, C39.1, C42.1, C43.2, D3.2 (GND), D4.1 (K), EPD_C1.1, EPD_C2.1, EPD_C5.1, EPD_C6.1, EPD_C7.1, EPD_C8.1, EPD_C9.1, EPD_C10.1, EPD_C11.1, EPD_C12.1, IC1.D2 (GND), IC2.B1 (IN/TRIG), IC2.B3 (GND), IC3.8 (GNDIO), IC3.9 (GND), IC9.B1 (VSEL), IC9.C1 (AGND), IC9.C2 (PGND_1), IC9.C3 (PGND_2), J1.8, J1.17, J1.MP1, J1.MP2, J2.3, J2.5, J4.A1_B12 (GND), J4.A12_B1 (GND), J4.SH1 (SHIELD), J4.SH2 (SHIELD), J4.SH3 (SHIELD), J4.SH4 (SHIELD), R1_USB.1, R2_EP_DR.1, R2_USB.2, R3.1, R9.1, R_TYPE_SEL.1, SJ1.1, SW_DN.1, SW_ENT.1, SW_UP.1, TP_BAT_GND.TP, TP_GND.TP, U1.P$74 (VSS_PAD), U1.P$75 (VSS_PAD), U1.P$76 (VSS_PAD), U1.P$77 (VSS_PAD), U1.P$78 (VSS_PAD), U1.P$79 (VSS_PAD), U1.P$80 (VSS_PAD), U1.P$81 (VSS_PAD), U1.P$82 (VSS_PAD), U1.P$83 (VSS_PAD), U1.P$84 (VSS_PAD), U1.P$85 (VSS_PAD), U1.P$86 (VSS_PAD), U1.P$87 (VSS_PAD), U1.P$88 (VSS_PAD), U1.P$89 (VSS_PAD), U1.P$90 (VSS_PAD), U1.P$B7 (VSS), U1.P$F23 (VSS_PA), U3.1 (CTG), U3.4 (GND), U3.6 (QSTRT), U3.9 (EP), X1.2, X1.4
HAPTIC_EN: IC2.A1 (EN), U1.P$U1 (P0.12)
IMU_INT1: IC3.5 (INT1), U1.P$N1 (P0.08)
IMU_INT2: IC3.6 (INT2), U1.P$P2 (P1.08)
LX1: IC9.B2 (SW1_1), IC9.B3 (SW1_2), L7.1
LX2: IC9.D2 (SW2_1), IC9.D3 (SW2_2), L7.2
MOSI: J1.14, U1.P$B13 (P0.03/AIN1)
unnamed: ANT1.1 (FEED), C4.1, C22.1, L1.2
unnamed: IC9.D1 (SCL), R4.2
unnamed: IC1.D1 (TS/MR), R9.2
unnamed: C2.1, U1.P$A23 (XC2), X1.3
unnamed: IC9.E1 (SDA), R2.2
unnamed: J4.A5 (CC1), R1_USB.2
unnamed: L2.2, L3.1
unnamed: IC3.1 (SDO), R3.2
unnamed: C1.1, U1.P$B24 (XC1), X1.1
unnamed: C3.1, L1.1, U1.P$H23 (ANT)
unnamed: C32.2, IC2.A2 (REG)
unnamed: C2-EP-DR.1, D2.1 (K), D4.2 (A)
unnamed: C9.1, U1.P$N24 (DEC5)
unnamed: R1_EP_DR.1, R_TYPE_SEL.2, SJ1.2
unnamed: C2-EP-DR.2, D5.2 (A), L5.1, Q3.3 (D)
unnamed: EPD_C2.2, J1.4
unnamed: EPD_C1.2, J1.5
unnamed: C20.1, U1.P$AC5 (DEC3V3)
unnamed: L2.1, U1.P$B3 (DCC)
unnamed: J4.B5 (CC2), R2_USB.1
unnamed: EPD_C6.2, J1.18
unnamed: EPD_C7.2, J1.19
unnamed: EPD_C8.2, J1.20
unnamed: EPD_C10.2, J1.22
unnamed: C13.1, U1.P$A18 (DEC2)
unnamed: EPD_C12.2, J1.24
OUT+: IC2.A3 (OUT+), TP_OP.TP
OUT-: IC2.C3 (OUT-), TP_ON.TP
P0.00/XL1: C17.2, U1.P$D2 (P0.00/XL1), X2.1
P0.01/XL2: C18.2, U1.P$F2 (P0.01/XL2), X2.2
P0.04: U1.P$J1 (P0.04/AIN2)
P0.09: U1.P$L24 (P0.09/NFC1)
P0.13: C30.2, R5.1, SW_UP.2
P0.14: C31.2, R8.1, SW_ENT.2
P0.19: U1.P$AC15 (P0.19)
P0.20: U1.P$AD16 (P0.20)
P0.21: U1.P$AC17 (P0.21)
P0.22: U1.P$AD18 (P0.22)
P0.23: U1.P$AC19 (P0.23)
P0.24: U1.P$AD20 (P0.24)
P0.25: U1.P$AC21 (P0.25)
P0.26: U1.P$G1 (P0.26)
P0.27: U1.P$H2 (P0.27)
P0.28: U1.P$B11 (P0.28/AIN4)
P0.29: U1.P$A10 (P0.29/AIN5)
P0.30: U1.P$B9 (P0.30/AIN6)
P0.31: U1.P$A8 (P0.31/AIN7)
P1.01: Q1.1 (G), R_PWR_EPD.1, U1.P$Y23 (P1.01)
P1.02: C29.2, R7.1, SW_DN.2, U1.P$W24 (P1.02)
P1.03: U1.P$V23 (P1.03)
P1.04: U1.P$U24 (P1.04)
P1.05: U1.P$T23 (P1.05)
P1.06: U1.P$R24 (P1.06)
P1.07: U1.P$P23 (P1.07)
P1.09: U1.P$R1 (P1.09)
P1.10: U1.P$A20 (P1.10)
P1.11: U1.P$B19 (P1.11)
P1.12: U1.P$B17 (P1.12)
P1.13: U1.P$A16 (P1.13)
P1.14: U1.P$B15 (P1.14)
P1.15: U1.P$A14 (P1.15)
PMIC_INT: IC1.A1 (!INT), U1.P$T2 (P0.11)
PO.13: U1.P$AD8 (P0.13)
PO.14: U1.P$AC9 (P0.14)
PREVGH: D5.1 (K), EPD_C9.2, J1.21
PREVGL: D2.2 (A), EPD_C11.2, J1.23
RESE: J1.3, Q3.2 (S), R1_EP_DR.2
RESET: J2.6, TP_RESET.TP, U1.P$AC13 (P0.18/RESET)
SCK: J1.13, U1.P$A12 (P0.02/AIN0)
SCL: IC1.B1 (SCL), IC2.C1 (SCL), IC3.12 (SCX), R4.1, R17.2, TP_SCL.TP, U1.P$M2 (P0.07), U3.7 (SCL)
SDA: IC1.C1 (SDA), IC2.B2 (SDA), IC3.2 (SDX), R2.1, R18.2, TP_SDA.TP, U1.P$L1 (P0.06), U3.8 (SDA)
SWDCLK: J2.4, TP_SWDCLK.TP, U1.P$AA24 (SWDCLK)
SWDIO: J2.2, TP_SWDIO.TP, U1.P$AC24 (SWDIO)
SWO: TP_SWO.TP, U1.P$AD22 (P1.00)
VBAT: C27.2, C37.2, IC1.C2 (BAT), TP_VBAT.TP, U3.2 (CELL), U3.3 (VDD)
VBUS: C21.1, C38.2, C42.2, C43.1, D3.5 (VBUS), IC1.A2 (IN), J4.A4_B9 (VBUS), J4.A9_B4 (VBUS), U1.P$AD2 (VBUS)
VREG: C23.2, C24.2, C39.2, IC1.B2 (SYS), IC9.A1 (EN), IC9.A2 (VIN_1), IC9.A3 (VIN_2), TP_VREG.TP

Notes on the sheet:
LiPo Charger
DC/DC
IMU
SWD
E-Paper Drive Circuit
E-Paper Display Connector
Fuel Gauge
Haptic Driver
Buttons
USB C Connector & ESD Protection

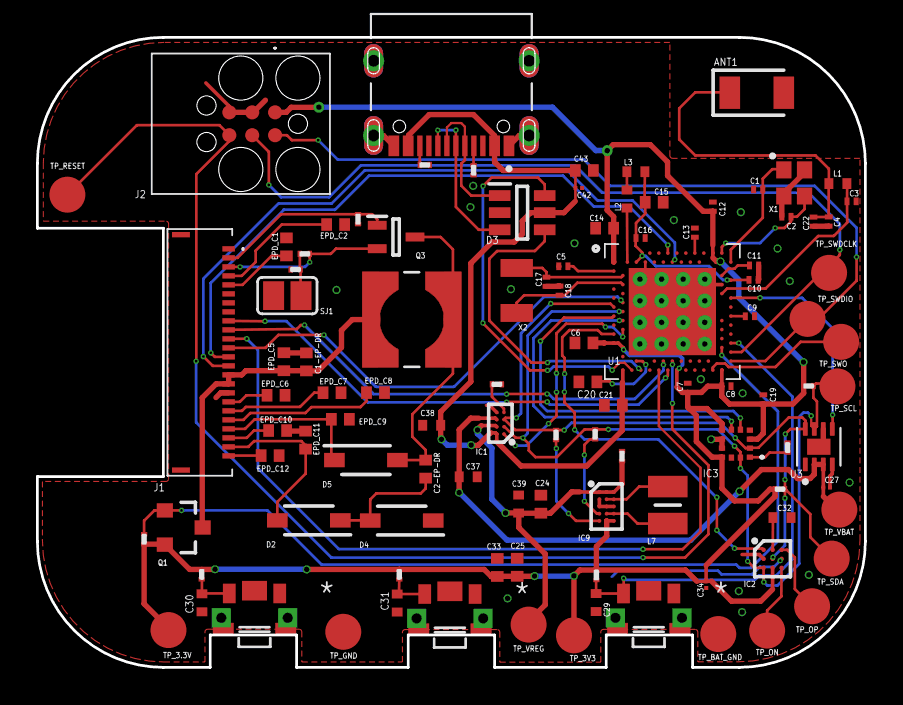
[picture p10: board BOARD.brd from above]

Board: 2 copper layers, 46.0 x 35.0 mm, 105 parts (0 on the bottom side), 70 nets.

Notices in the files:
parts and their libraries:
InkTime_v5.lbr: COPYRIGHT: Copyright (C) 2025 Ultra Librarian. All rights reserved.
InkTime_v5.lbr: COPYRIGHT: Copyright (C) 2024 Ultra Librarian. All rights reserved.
